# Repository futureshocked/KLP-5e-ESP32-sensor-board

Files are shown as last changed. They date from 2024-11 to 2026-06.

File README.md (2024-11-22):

View this project on [CADLAB.io](https://cadlab.io/project/28685). 

## Project Summary: Custom IoT PCB with ESP32-C3-02 and TP4056 Li-ion Charger

This project involves the design and development of a custom PCB for an IoT application powered by the ESP32-C3-02 SoC. The board includes integrated power management features using the TP4056 Li-ion battery charger IC, enabling efficient and safe charging of a single-cell Li-ion battery.

### Key Features

- **Microcontroller**: ESP32-C3-02 SoC for Wi-Fi and BLE connectivity.
- **Power Management**: TP4056 IC for single-cell Li-ion battery charging with thermal regulation.
- **Battery Protection**: Integrated under-voltage lockout and trickle charging.
- **Sensors and Modules**:
  - BME280 for temperature, humidity, and pressure sensing.
  - Ambient light and sound sensors.
  - Mini SD card reader for data storage.
  - Flash memory for additional storage.
- **Display**: I2C OLED for real-time data visualization.
- **Power Inputs**:
  - USB-C connector for charging and data transfer.
  - LiPo battery connector with onboard charging circuitry.
- **Indicators**: LED indicators for charge status (charging and full).

### Design Highlights

1. **Power Supply Integration**:
   - USB-C provides power for both charging and system operation.
   - TP4056 handles battery charging and protection.
   - Power supplied to the ESP32-C3-02 is regulated for stability.

2. **Modular Architecture**:
   - Supports various sensors and peripherals for IoT applications.
   - Expandable via additional I2C devices.

3. **Safe and Efficient Charging**:
   - Programmable charging current using an external resistor.
   - Automatic charge termination and battery protection.

4. **Compact and Reliable Layout**:
   - Optimized PCB traces for minimal power loss.
   - Thermal management for the TP4056 and other components.

### Applications

- IoT edge devices for environmental monitoring.
- Battery-powered data logging systems.
- Prototyping platform for ESP32-based projects.

### Repository Contents

- **Schematic and PCB Layout**: KiCad files for the board design.
- **Firmware**: Source code for the ESP32-C3-02 to interface with sensors and peripherals.
- **Documentation**:
  - Datasheets for the TP4056 and other components.
  - Assembly instructions.
  - Testing procedures.
- **License**: MIT License.

This repository is a complete resource for designing and building a robust IoT solution with integrated power management and ESP32 connectivity.

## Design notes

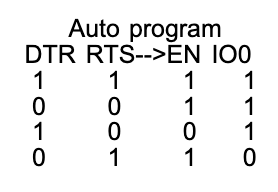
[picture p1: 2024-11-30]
KiCad project/Images/Auto program truth table.png

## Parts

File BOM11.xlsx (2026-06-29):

DESIGNATOR | QTY | VALUE | MPN | MANUFACTURER | Procurement Type | PACKAGE | DESCRIPTION
> C1, C2, C5, C8, C10, C13-C16, C18, C20, C21 | 12 | 0.1u | C0805C104K4RAC | KEMET | C | 805 | Multilayer Ceramic Capacitors MLCC - SMD/SMT 16V 0.1uF X7R 0805 10%
> C3, C4, C7, C12 | 4 | 10u | T491A106K010AT7280 | KEMET | C | 1206 | T491, Tantalum, MnO2 Tantalum, Commercial Grade, 10 uF, 10%, 10 VDC, 125C, -55C, 85C, SMD, MnO2, Molded, 6 % , 3.8 Ohms, 1000 nA, 58.6 mg, 3216, 1.6mm, Height Max = 1.8mm, 9000, 156 Weeks
> C6, C11, C19, C22 | 4 | 1u | C0805C105K4RACTU | KEMET | C | 805 | Multilayer Ceramic Capacitors MLCC - SMD/SMT 16V 1uF X7R 0805 10%
C9 | 1 | 4.7u | T491A475K010AT7280 | KEMET | C | 1206 | T491, Tantalum, MnO2 Tantalum, Commercial Grade, 4.7 uF, 10%, 10 VDC, 125C, -55C, 85C, SMD, MnO2, Molded, 6 % , 4 Ohms, 500 nA, 58.6 mg, 3216, 1.6mm, Height Max = 1.8mm, 9000, 156 Weeks
C17 | 1 | 10n | C0805C103M4RACTU | KEMET | C | 805 | Multilayer Ceramic Capacitors MLCC - SMD/SMT 16V 0.01uF X7R 0805 20%
> D1, D4, D6 | 3 | RED | LTST-C170KRKT | Lite-On | C | 805 | Standard LEDs - SMD Red Clear 631nm
> D2, D5 | 2 | GREEN | LTST-C170GKT | Lite-On | C | 805 | LED,SMD,0805,Green,6mcd,130deg Lite-On LTST-C170GKT, CHIPLED 0805 Series Green LED, 569 nm 2012 (0805), Rectangle Lens SMD package
D3 | 1 | BLUE | LTST-C170TBKT | Lite-On | C | 805 | LED,SMD,0805,Blue,28mcd,130deg
F1 | 1 | 0ZCH0110AF2E | 0ZCH0110AF2E | Belfuse | C | 1210 | 1210 SMT PPTC | 1.10 Ih | 16V
J1 | 1 | USB_C_Receptacle | Footprints:BELFUSE_SS-52400-002 | BELFUSE Stewart Connector | SS-52400-003 for standard 1.6 mm PCB thickness | USB 2.0-only Type-C Receptacle connector. See https://www.snapeda.com/parts/SS-52400-002/Bel%20Fuse/view-part/?ref=search&t=BELFUSE_SS-52400-002
J2 | 1 | JST_2mm_LiPo | JST_B2B-PH-SM4-TB | JST | C |  | 2 Pin 2mm JST Battery Connector
J3 | 1 | GSD090012SEU | GSD090012SEU | Amphenol | C |  | Memory Card Connectors SD CARD CONNECTOR 9 POS, SMT
> J4, J5 | 2 | B4B-XH-AM | B4B-XH-AM | JST | C |  | Connector header vertical 4pos 2.5mm
J6 | 1 | Conn_01x05 | PZ254V-11-05P |  | C |  | Header 1X5, 2.54mm
MK1 | 1 | CMC-5042PF-AC | CMC-5042PF-AC | CUI INC | C |  | Microphone
Q1 | 1 | TEMT6000X01 | TEMT6000X01 | VISHAY | C | 4 mm x 2 mm x 1.05 mm | Ambient Light Sensors Ambient Light Sensor AEC-Q101 Qualified
> Q2, Q3 | 2 | BC817 | BC817 |  | C | SOT-23 | 0.8A Ic, 45V Vce, NPN Transistor, SOT-23
> R1, R2, R19, R23, R30, R32-R34 | 8 | 10K | 0805W8F1002T5E |  | C | 805 | SMD resistor, 0805, 125mW, 1%
> R3, R4 | 2 | 5k1 | 0805W8F5101T5E |  | C | 0805 | SMD resistor, 0805, 125mW, 1%
> R5, R26, R28 | 3 | 2K | 0805W8F2001T5E |  | C | 0805 | SMD resistor, 0805, 125mW, 1%
R6 | 1 | 20K | 0805W8F2002T5E |  | C | 0805 | SMD resistor, 0805, 125mW, 1%
> R7-R9 | 3 | 470 | 0805W8F4700T5E |  | C | 0805 | SMD resistor, 0805, 125mW, 1%
> R10, R14, R18 | 3 | 330 | 0805W8F3300T5E |  | C | 0805 | SMD resistor, 0805, 125mW, 1%
R11 | 1 | 1K | 0805W8F1001T5E |  | C | 0805 | SMD resistor, 0805, 125mW, 1%
R12 | 1 | 22K1 | FRC0805F2212TS |  | C | 0805 | SMD resistor, 0805, 125mW, 1%
R13 | 1 | 47K5 | 0805W8F4752T5E |  | C | 0805 | SMD resistor, 0805, 125mW, 1%
> R15-R17, R20-R22 | 6 | 50 | ARG05FTC0500 |  | C | 0805 | SMD resistor, 0805, 125mW, 1%
> R24, R25 | 2 | 4K7 | 0805W8F4701T5E |  | C | 0805 | SMD resistor, 0805, 125mW, 1%
> R27, R29 | 2 | 1M | CRCW08051M00FKEA |  | C | 0805 | SMD resistor, 0805, 125mW, 1%
R31 | 1 | 100K | 0805W8F1003T5E |  | C | 0805 | SMD resistor, 0805, 125mW, 1%
> SW1, SW2 | 2 | 1101NE | USLPT2819 Family | TE Connectivity | USLPT2819 MSLPT (Mini size) | SMD_6x3.5mm_h2.5mm. Please see https://www.snapeda.com/parts/USLPT2819DT2TR/TE%20Connectivity/view-part/?ref=search&t=SMD%20switch
U1 | 1 | MCP73871 | MCP73871-4CCI/ML | Microchip | C | QFN-20 | Single cell, Li-Ion/Li-Po charge management controller
U2 | 1 | LM1117MPX-3.3_NOPB | LM1117MPX-3.3/NOPB | Texas Instruments | C | SOT-223-4 | Space saving 800-mA low-dropout linear regulator with internal current limit
U3 | 1 | ESP32-C3-WROOM-02-H4 | ESP32-C3-WROOM-02-H4 | Espressif | C |  | Multiprotocol Modules SMD module, ESP32-C3, 4MB SPI flash, PCB antenna
U4 | 1 | CP2102N-A02-GQFN20 | CP2102N-A02-GQFN20 | Silicon Laboratories | C | QFN20 | USB to UART Bridge
U5 | 1 | USBLC6-2SC6 | USBLC6-2SC6 | STMicroelectronics | C | SOT-23-6 | ESD Suppressors / TVS Diodes ESD Protection Low Cap
U6 | 1 | W25Q32JVSSIQ | W25Q32JVSSIQ | Winbond | C | SOIC-8 | NOR Flash spiFlash, 32M-bit, 4Kb Uniform Sector
U7 | 1 | BME280 | BME280 | Bosch | C | LGA-8 | Air Quality Sensor MEMS humidity, pressure and temperature sensor
U8 | 1 | MAX4466EXK+T | MAX4466EXK+T | Analog Devices Inc. | C | SC-70-5 | Microphone Preamplifier

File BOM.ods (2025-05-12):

DESIGNATOR | QTY | VALUE | MANUF. PART No | MANUFACTURER | PACKAGE | DESCRIPTION
C1, C2, C5, C8, C10, C13-C16, C18, C21, C23 | 12 | 0.1u | C0805C104K4RAC | KEMET | 0805 | Multilayer Ceramic Capacitors MLCC - SMD/SMT 16V 0.1uF X7R 0805 10%
C3, C4, C7, C12 | 4 | 10u | T491A106K010AT7280 | KEMET | 1206 | T491, Tantalum, MnO2 Tantalum, Commercial Grade, 10 uF, 10%, 10 VDC, 125C, -55C, 85C, SMD, MnO2, Molded, 6 % , 3.8 Ohms, 1000 nA, 58.6 mg, 3216, 1.6mm, Height Max = 1.8mm, 9000, 156 Weeks
C6, C11, C22 | 3 | 1u | C0805C105K4RACTU | KEMET | 0805 | Multilayer Ceramic Capacitors MLCC - SMD/SMT 16V 1uF X7R 0805 10%
C9 | 1 | 4.7u | T491A475K010AT7280 | KEMET | 1206 | T491, Tantalum, MnO2 Tantalum, Commercial Grade, 4.7 uF, 10%, 10 VDC, 125C, -55C, 85C, SMD, MnO2, Molded, 6 % , 4 Ohms, 500 nA, 58.6 mg, 3216, 1.6mm, Height Max = 1.8mm, 9000, 156 Weeks
C17, C24, C25 | 3 | 10n | C0603C103K4RACTU | KEMET | 0603 | Multilayer Ceramic Capacitors MLCC - SMD/SMT 16V 0.01uF X7R 0603 10%
C19 | 1 | 10uF | C1206C106K4RAC | KEMET | 1206 | Multilayer Ceramic Capacitors MLCC - SMD/SMT 16V 10uF X7R 1206 10%
C20 | 1 | 100pF | C0603C101K4RACTU | KEMET | 0603 | Multilayer Ceramic Capacitors MLCC - SMD/SMT 16V 100pF X7R 0603 10%
D1, D4, D6 | 3 | RED | LTST-C170KRKT | Lite-On | 0805 | Standard LEDs - SMD Red Clear 631nm
D2, D5 | 2 | GREEN | LTST-C170GKT | Lite-On | 0805 | LED,SMD,0805,Green,6mcd,130deg Lite-On LTST-C170GKT, CHIPLED 0805 Series Green LED, 569 nm 2012 (0805), Rectangle Lens SMD package
D3 | 1 | BLUE | LTST-C170TBKT | Lite-On | 0805 | LED,SMD,0805,Blue,28mcd,130deg
F1 | 1 | 0ZCH0110AF2E | 0ZCH0110AF2E | Belfuse | 1210 | 1210 SMT PPTC | 1.10 Ih | 16V
J1 | 1 | USB_C_Receptacle | SS-52400-002 | STEWART CONNECTOR | USB Type-C | USB 2.0-only Type-C Receptacle connector
J2 | 1 | JST_2mm_LiPo | PHR-2 | JST |  | 2 Pin 2mm JST Battery Connector
J3 | 1 | GSD090012SEU | GSD090012SEU | Amphenol |  | Memory Card Connectors SD CARD CONNECTOR 9 POS, SMT
J4, J5 | 2 | B4B-XH-AM | B4B-XH-AM | JST |  | Connector header vertical 4pos 2.5mm
J6 | 1 | Conn_01x05 |  |  |  | Header 1X5, 2.54mm
L1 | 1 |  | FBMJ2125HM330 | TAIYO YUDEN | 0805 | Ferrite Bead 0805 4A 33OHMS 25%
MK1 | 1 | CMC-5042PF-AC | CMC-5042PF-AC | CUI INC
Q1 | 1 | TEMT6000X01 | TEMT6000X01 | VISHAY | 4 mm x 2 mm x 1.05 mm | Ambient Light Sensors Ambient Light Sensor AEC-Q101 Qualified
Q2, Q3 | 2 | BC817 | BC817 |  | SOT-23 | 0.8A Ic, 45V Vce, NPN Transistor, SOT-23
R1, R2, R19, R23, R32-R34 | 7 | 10K |  |  | 805 | SMD resistor, 0805, 125mW, 1%
R3, R4 | 2 | 5k1 |  |  | 0805 | SMD resistor, 0805, 125mW, 1%
R5, R26, R28 | 3 | 2K |  |  | 0805 | SMD resistor, 0805, 125mW, 1%
R6 | 1 | 20K |  |  | 0805 | SMD resistor, 0805, 125mW, 1%
R7-R9 | 3 | 470 |  |  | 0805 | SMD resistor, 0805, 125mW, 1%
R10, R14, R18 | 3 | 330 |  |  | 0805 | SMD resistor, 0805, 125mW, 1%
R11, R30 | 2 | 1K |  |  | 0805 | SMD resistor, 0805, 125mW, 1%
R12 | 1 | 22K1 |  |  | 0805 | SMD resistor, 0805, 125mW, 1%
R13 | 1 | 47K5 |  |  | 0805 | SMD resistor, 0805, 125mW, 1%
R15-R17, R20-R22 | 6 | 50 |  |  | 0805 | SMD resistor, 0805, 125mW, 1%
R24, R25 | 2 | 4K7 |  |  | 0805 | SMD resistor, 0805, 125mW, 1%
R27, R29 | 2 | 1M |  |  | 0805 | SMD resistor, 0805, 125mW, 1%
R31 | 1 | 22K |  |  | 0805 | SMD resistor, 0805, 125mW, 1%
SW1, SW2 | 2 | TL3305AF260QG | TL3305AF260QG | E-Switch |  | Tactile Switches 50mA 12VDC SPST, NO 3.8mm Act 260gf
U1 | 1 | MCP73871 | MCP73871-4CCI/ML | Microchip | QFN-20 | Single cell, Li-Ion/Li-Po charge management controller
U2 | 1 | LM1117MPX-3.3_NOPB | LM1117MPX-3.3/NOPB | Texas Instruments | SOT-223-4 | Space saving 800-mA low-dropout linear regulator with internal current limit
U3 | 1 | ESP32-C3-WROOM-02-H4 | ESP32-C3-WROOM-02-H4 | Espressif |  | Multiprotocol Modules SMD module, ESP32-C3, 4MB SPI flash, PCB antenna
U4 | 1 | CP2102N-A02-GQFN20 | CP2102N-A02-GQFN20 | Silicon Laboratories | QFN20 | USB to UART Bridge
U5 | 1 | USBLC6-2SC6 | USBLC6-2SC6 | STMicroelectronics | SOT-23-6 | ESD Suppressors / TVS Diodes ESD Protection Low Cap
U6 | 1 | W25Q32JVSSIQ | W25Q32JVSSIQ | Winbond | SOIC-8 | NOR Flash spiFlash, 32M-bit, 4Kb Uniform Sector
U7 | 1 | BME280 | BME280 | Bosch | LGA-8 | Air Quality Sensor MEMS humidity, pressure and temperature sensor
U8 | 1 | MAX4466EXK+T | MAX4466EXK+T | Analog Devices Inc. | SC-70-5 | Microphone Preamplifier
VR1 | 1 | 35WR100KLFTR | 35WR100KLFTR | TT Electronics |  | Trimmer Resistor - SMD 3mm 100K Open Type

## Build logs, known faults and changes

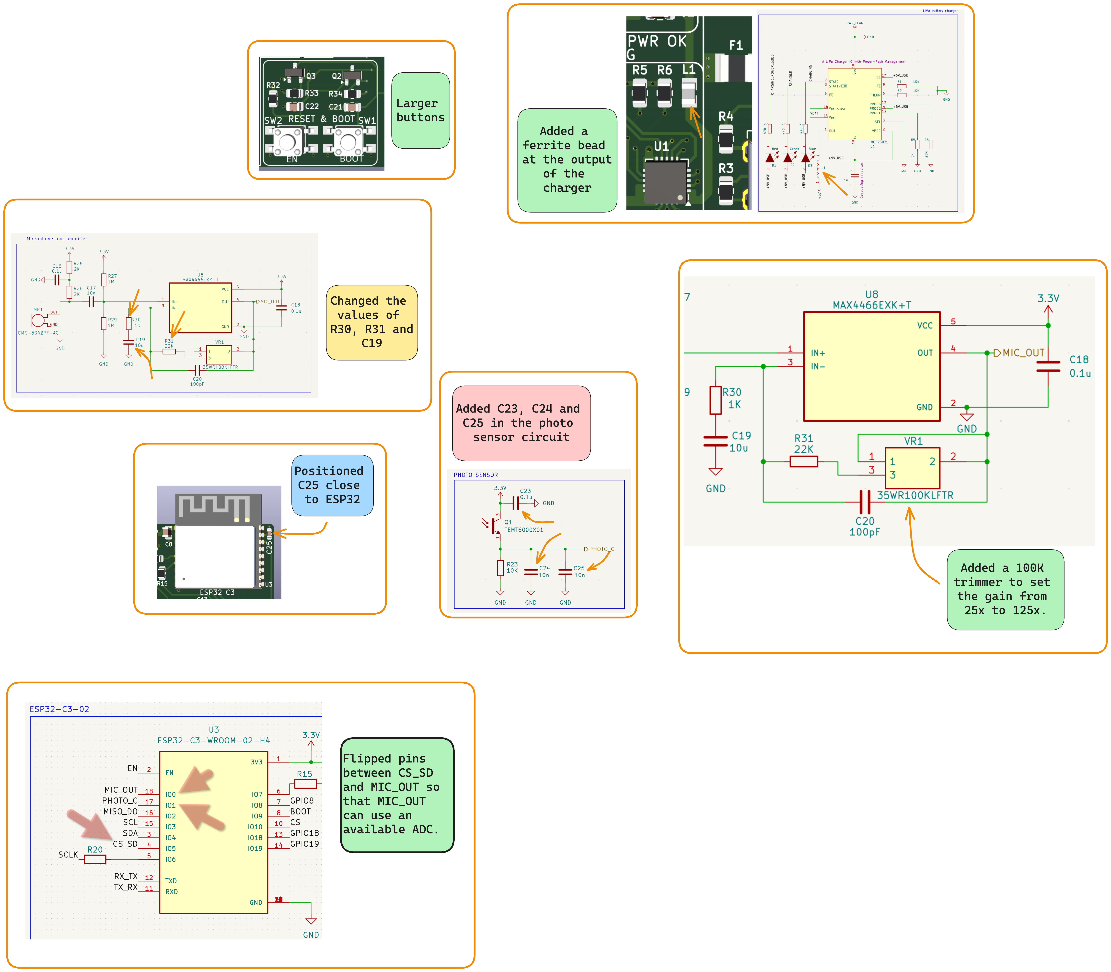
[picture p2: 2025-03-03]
ESP32 PCB prototype 2 improvements and fixes.png

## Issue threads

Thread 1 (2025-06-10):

Any solution found for the CP2102 TX, RX LEDs not blinking on data communication ?

rickygai, 2025-06-10:
at Udemy video Section 4, 25.210 13:01, the R14 and R18 is 470 ohm, based on latest schematic downloaded and in this video, R14 and R18 changed to 330ohm.

Does this change resolve the blinking problem of TX and RX LEDs of CP2102 ?

a1wolfe, 2025-09-07:
Hi Ricky, I had my board built with 330 ohms and that did not resolve the issue.

The real issue is that the CP2102 GPIO pins are configured as inputs by default (Section 4.3.1 of datasheet). The TXT/RXT blinking behaviors are alternate functions for GPIO.2 and GPIO.3.

The only way I found to reconfigure the CP2102 GPIO function is using Simplicity Studio by Silicon Labs. You can download the installers here: https://www.silabs.com/software-and-tools/simplicity-studio

After installation, open Simplicity Studio and connect your board. The CP2102 should show up, and you can then select the tab for compatible software. This will take you to another sub-tool called Xpress Configurator.

In Xpress Configuration, here is where you can change the alternate function mode for the GPIOs.

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

The tools are pretty intuitive, but there is an app note from Silicon Labs here with more info: https://www.silabs.com/documents/public/application-notes/AN721.pdf

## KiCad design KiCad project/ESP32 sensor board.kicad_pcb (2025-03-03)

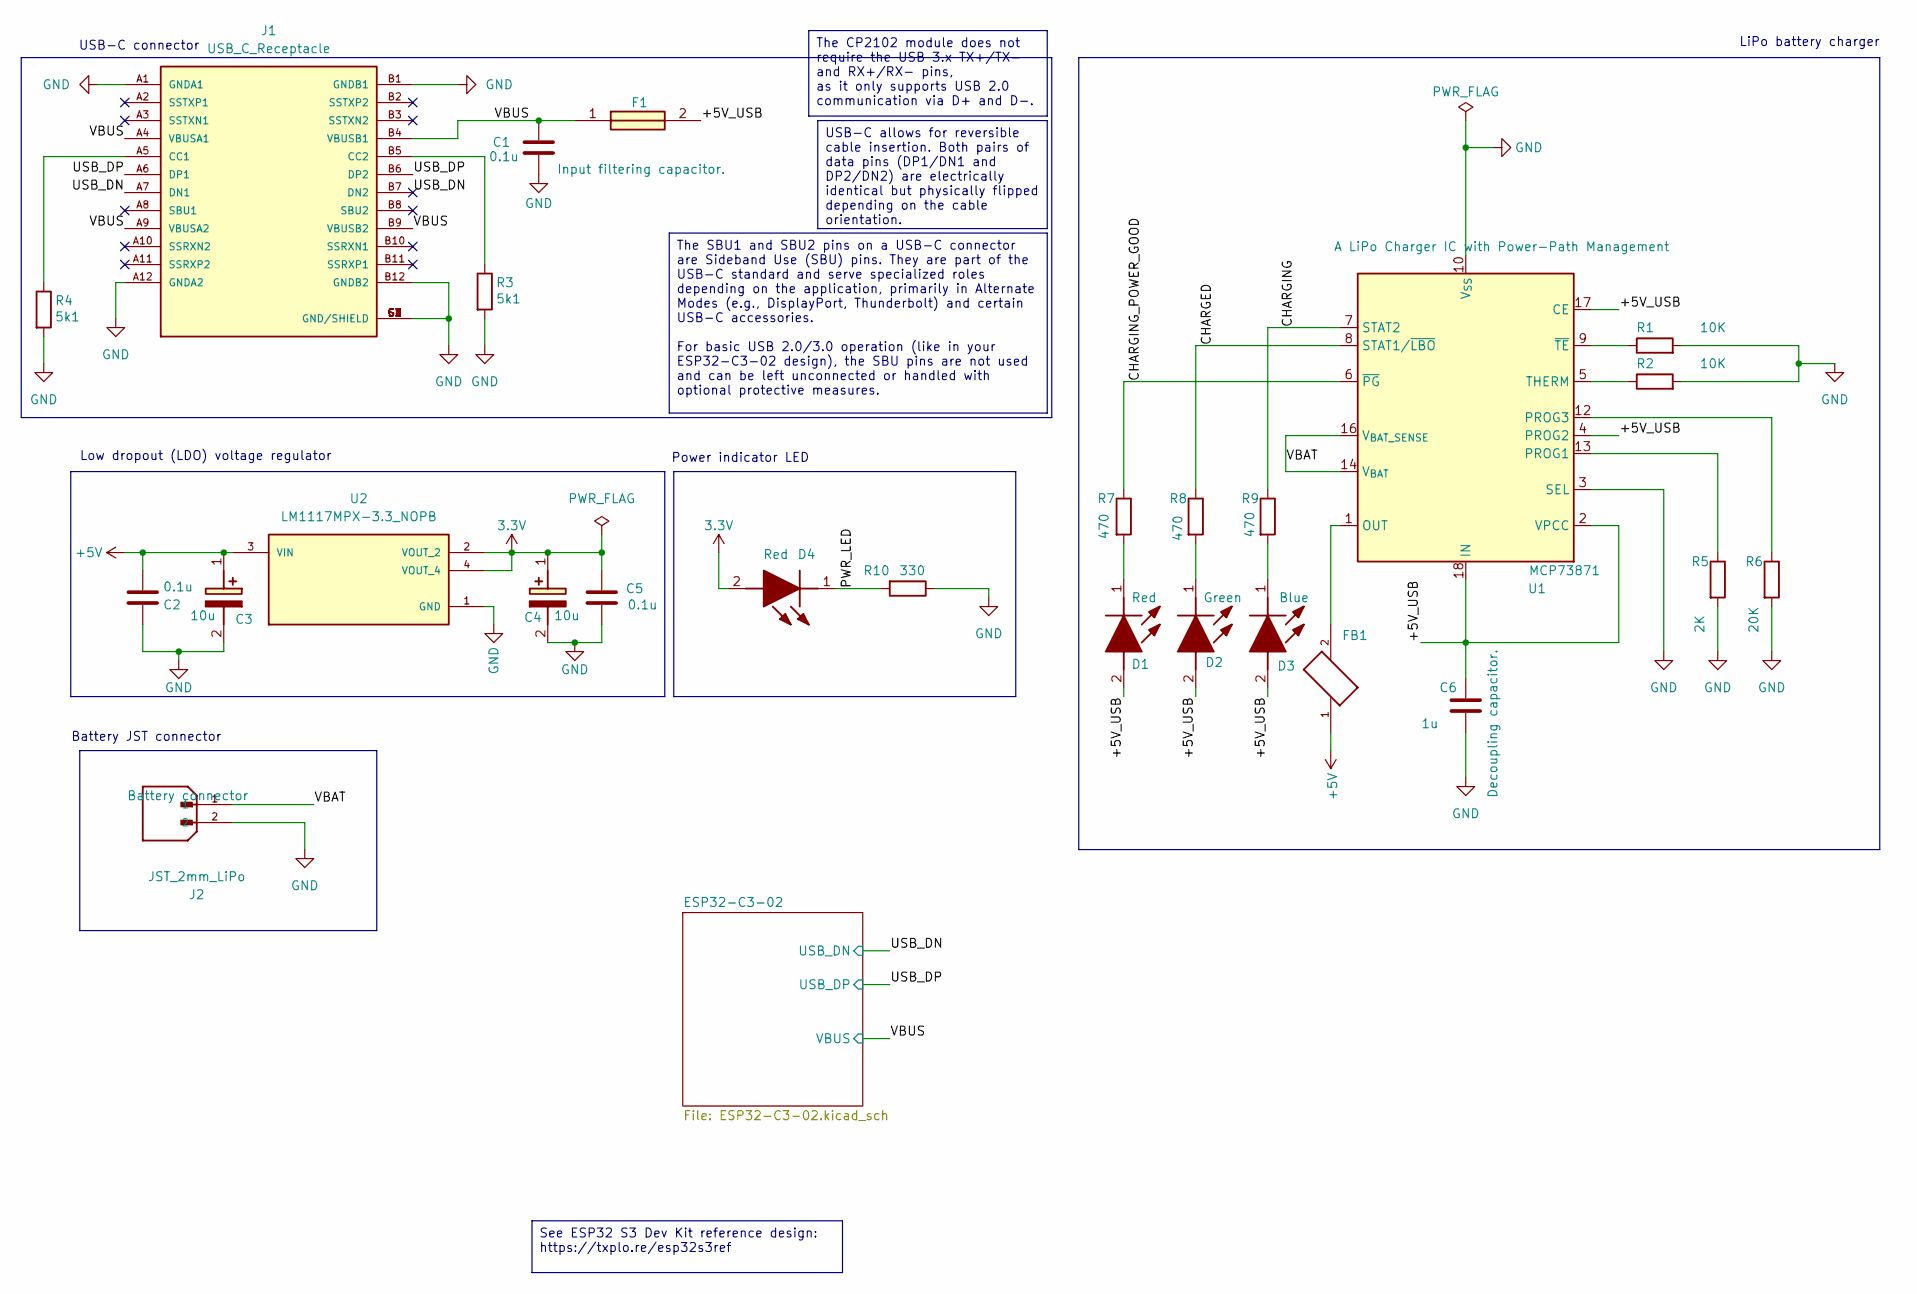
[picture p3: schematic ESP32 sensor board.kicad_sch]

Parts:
C1, C2, C5: 0.1u; C_0805_2012Metric; Voltage 1kV; Tolerance 100%
C3, C4: 10u; T491A; Voltage 1kV; Tolerance 100%; Manufacturer_Part_Number T491A106K010AT7280; Mouser Part Number 80-T491A106K107280
C6: 1u; C_0805_2012Metric; Voltage 1kV; Tolerance 100%
D1, D4: Red; LEDC2012X120N; Manufacturer_Part_Number LTST-C170KRKT; Mouser Part Number 859-LTST-C170KRKT
D2: Green; LEDC2012X120N; Manufacturer_Part_Number LTST-C170GKT; Mouser Part Number 859-LTST-C170GKT
D3: Blue; LEDC2012X120N; Manufacturer_Part_Number LTST-C170TBKT; Mouser Part Number 859-LTST-C170TBKT
F1: 0ZCH0110AF2E; FUSC3226X100N; Manufacturer_Part_Number 0ZCH0110AF2E
FB1: FBMJ2125HM330-T; BEADC2012X105N
J1: USB_C_Receptacle; BELFUSE_SS-52400-002; PARTREV A0
J2: JST_2mm_LiPo; JST_B2B-PH-SM4-TB; Manufacturer_Part_Number ?
R1, R2: 10K; R_0805_2012Metric
R3, R4: 5k1; R_0805_2012Metric
R5: 2K; R_0805_2012Metric
R6: 20K; R_0805_2012Metric
R7, R8, R9: 470; R_0805_2012Metric
R10: 330; R_0805_2012Metric
U1: MCP73871; QFN-20-1EP_4x4mm_P0.5mm_EP2.5x2.5mm; Manufacturer_Part_Number MCP73871-4CCI/ML
U2: LM1117MPX-3.3_NOPB; VREG_LM1117MPX-3.3; Mouser Part Number 926-LM1117MPX3.3NOPB

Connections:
3.3V: C4.1 (+), C5.1, D4.2 (A), U2.2 (VOUT_2), U2.4 (VOUT_4); also elsewhere on the board
+5V: C2.1, C3.1 (+), FB1.1, U2.3 (VIN)
/+5V_USB: C6.1, D1.2 (A), D2.2 (A), D3.2 (A), F1.2, U1.2 (VPCC), U1.4 (PROG2), U1.17 (CE), U1.18 (IN), U1.19 (IN)
/CHARGED: R8.1, U1.8 (STAT1/~LBO)
/CHARGING: R9.1, U1.7 (STAT2)
/CHARGING_POWER_GOOD: R7.1, U1.6 (~PG)
/PWR_LED: D4.1 (K), R10.2
/USB_DN: J1.A7 (DN1), J1.B7 (DN2); also elsewhere on the board
/USB_DP: J1.A6 (DP1), J1.B6 (DP2); also elsewhere on the board
/VBAT: J2.1, U1.14 (V_{BAT}), U1.15 (V_{BAT}), U1.16 (V_{BAT_SENSE})
/VBUS: C1.1, F1.1, J1.A4 (VBUSA1), J1.A9 (VBUSA2), J1.B4 (VBUSB1), J1.B9 (VBUSB2); also elsewhere on the board
GND: C1.2, C2.2, C3.2 (-), C4.2 (-), C5.2, C6.2, J1.A1 (GNDA1), J1.A12 (GNDA2), J1.B1 (GNDB1), J1.B12 (GNDB2), J1.G1 (GND/SHIELD), J1.G2 (GND/SHIELD), J1.G3 (GND/SHIELD), J1.G4 (GND/SHIELD), J1.S1 (GND/SHIELD), J1.S2 (GND/SHIELD), J1.S3 (GND/SHIELD), J1.S4 (GND/SHIELD), J2.2, R1.2, R2.2, R3.2, R4.2, R5.2, R6.2, R10.1, U1.3 (SEL), U1.10 (V_{SS}), U1.11 (V_{SS}), U1.21 (V_{SS}), U2.1 (GND); also elsewhere on the board
unnamed: D1.1 (K), R7.2
unnamed: D2.1 (K), R8.2
unnamed: D3.1 (K), R9.2
unnamed: FB1.2, U1.1 (OUT), U1.20 (OUT)
unnamed: J1.A5 (CC1), R4.1
unnamed: J1.B5 (CC2), R3.1
unnamed: R5.1, U1.13 (PROG1)
unnamed: R6.1, U1.12 (PROG3)
unnamed: R2.1, U1.5 (THERM)
unnamed: R1.1, U1.9 (~TE)

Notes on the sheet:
USB-C connector
LiPo battery charger
Power indicator LED
Low dropout (LDO) voltage regulator
Battery JST connector
The CP2102 module does not require the USB 3.x TX+/TX- and RX+/RX- pins, as it only supports USB 2.0 communication via D+ and D-.
See ESP32 S3 Dev Kit reference design: https://txplo.re/esp32s3ref
The SBU1 and SBU2 pins on a USB-C connector are Sideband Use (SBU) pins. They are part of the USB-C standard and serve specialized roles depending on the application, primarily in Alternate Modes (e.g., DisplayPort, Thunderbolt) and certain USB-C accessories. For basic USB 2.0/3.0 operation (like i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
USB-C allows for reversible cable insertion. Both pairs of data pins (DP1/DN1 and DP2/DN2) are electrically identical but physically flipped depending on the cable orientation.

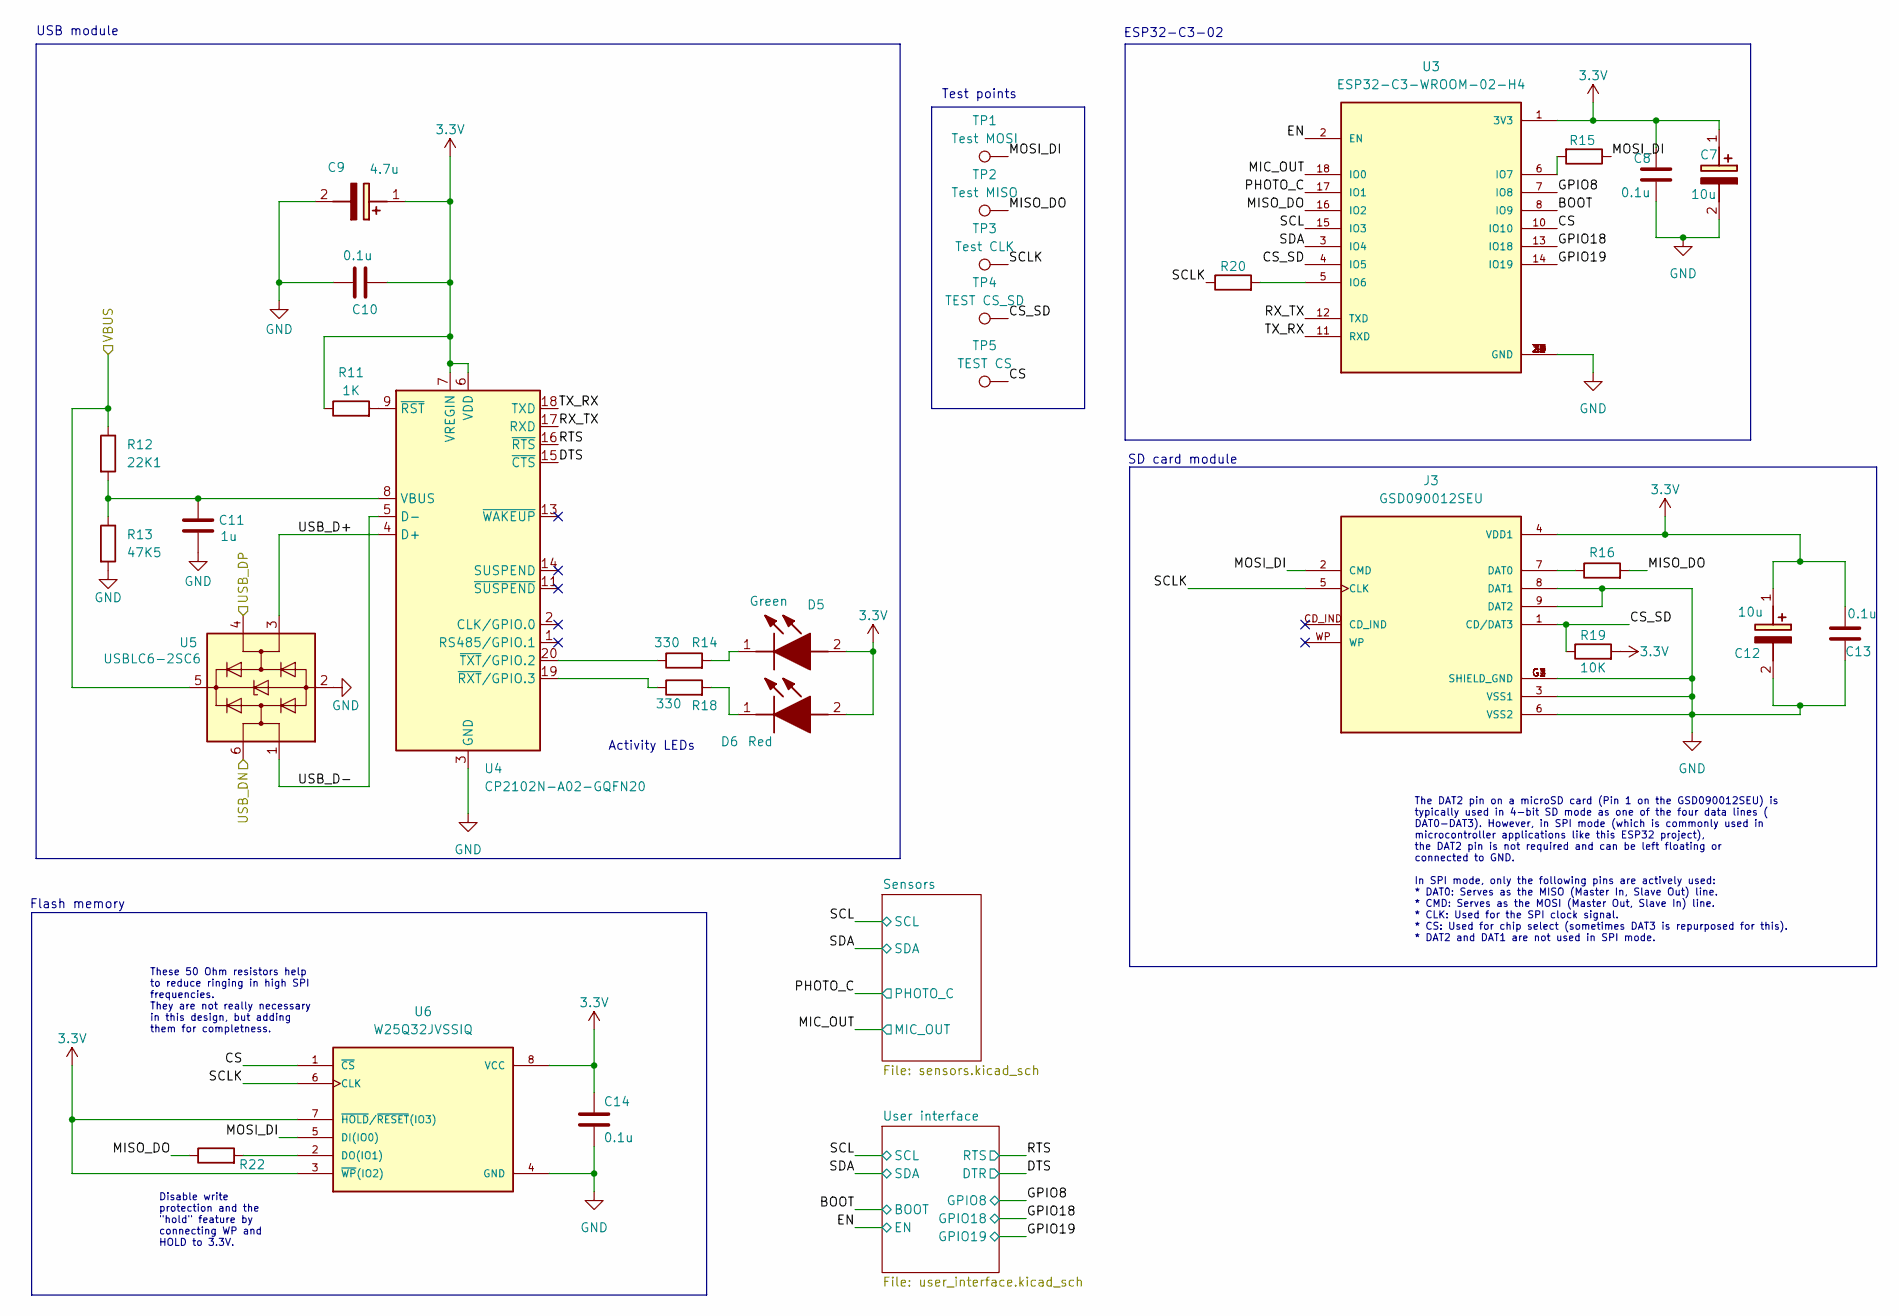
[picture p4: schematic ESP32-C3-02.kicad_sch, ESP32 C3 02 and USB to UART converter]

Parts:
C7, C12: 10u; T491A; Voltage 1kV; Tolerance 100%; Manufacturer_Part_Number T491A106K010AT7280; Mouser Part Number 80-T491A106K107280
C8, C10, C13, C14: 0.1u; C_0805_2012Metric; Voltage 1kV; Tolerance 100%
C9: 4.7u; T491A; Voltage 1kV; Tolerance 100%; Manufacturer_Part_Number T491A106K010AT7280; Mouser Part Number 80-T491A106K107280
C11: 1u; C_0805_2012Metric; Voltage 1kV; Tolerance 100%
D5: Green; LEDC2012X120N; Manufacturer_Part_Number LTST-C170GKT; Mouser Part Number 859-LTST-C170GKT
D6: Red; LEDC2012X120N; Manufacturer_Part_Number LTST-C170KRKT; Mouser Part Number 859-LTST-C170KRKT
J3: GSD090012SEU; AMPHENOL_GSD090012SEU; PARTREV E
R11: 1K; R_0805_2012Metric
R12: 22K1; R_0805_2012Metric
R13: 47K5; R_0805_2012Metric
R14, R18: 330; R_0805_2012Metric
R15, R16, R20, R22: 50; R_0805_2012Metric
R19: 10K; R_0805_2012Metric
TP1: Test MOSI; TestPoint_Pad_D1.0mm
TP2: Test MISO; TestPoint_Pad_D1.0mm
TP3: Test CLK; TestPoint_Pad_D1.0mm
TP4: TEST CS_SD; TestPoint_Pad_D1.0mm
TP5: TEST CS; TestPoint_Pad_D1.0mm
U3: ESP32-C3-WROOM-02-H4; MODULE_ESP32-C3-WROOM-02-H4; Manufacturer_Part_Number ESP32-C3-WROOM-02-H4
U4: CP2102N-A02-GQFN20; SiliconLabs_QFN-20-1EP_3x3mm_P0.5mm_EP1.8x1.8mm; Manufacturer_Part_Number CP2102N-A02-GQFN20
U5: USBLC6-2SC6; SOT-23-6; Manufacturer_Part_Number USBLC6-2SC6; Mouser Part Number 511-USBLC6-2SC6
U6: W25Q32JVSSIQ; SOIC127P790X216-8N; M_PART_NUMBER W25QXX

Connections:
3.3V: C7.1 (+), C8.1, C9.1 (+), C10.1, C12.1 (+), C13.2, C14.1, D5.2 (A), D6.2 (A), J3.4 (VDD1), R11.1, R19.2, U3.1 (3V3), U4.6 (VDD), U4.7 (VREGIN), U6.3 (~WP(IO2)), U6.7 (~HOLD/~RESET(IO3)), U6.8 (VCC); also elsewhere on the board
/ESP32-C3-02/BOOT: U3.8 (IO9); also elsewhere on the board
/ESP32-C3-02/CS: TP5.1, U3.10 (IO10), U6.1 (~CS)
/ESP32-C3-02/CS_SD: J3.1 (CD/DAT3), R19.1, TP4.1, U3.4 (IO5)
/ESP32-C3-02/DTS: U4.15 (~CTS); also elsewhere on the board
/ESP32-C3-02/EN: U3.2 (EN); also elsewhere on the board
/ESP32-C3-02/GPIO8: U3.7 (IO8); also elsewhere on the board
/ESP32-C3-02/GPIO18: U3.13 (IO18); also elsewhere on the board
/ESP32-C3-02/GPIO19: U3.14 (IO19); also elsewhere on the board
/ESP32-C3-02/MIC_OUT: U3.18 (IO0); also elsewhere on the board
/ESP32-C3-02/MISO_DO: R16.2, R22.1, TP2.1, U3.16 (IO2)
/ESP32-C3-02/MOSI_DI: J3.2 (CMD), R15.1, TP1.1, U6.5 (DI(IO0))
/ESP32-C3-02/PHOTO_C: U3.17 (IO1); also elsewhere on the board
/ESP32-C3-02/RTS: U4.16 (~RTS); also elsewhere on the board
/ESP32-C3-02/RX_TX: U3.12 (TXD), U4.17 (RXD)
/ESP32-C3-02/SCL: U3.15 (IO3); also elsewhere on the board
/ESP32-C3-02/SCLK: J3.5 (CLK), R20.1, TP3.1, U6.6 (CLK)
/ESP32-C3-02/SDA: U3.3 (IO4); also elsewhere on the board
/ESP32-C3-02/TX_RX: U3.11 (RXD), U4.18 (TXD)
/ESP32-C3-02/USB_D+: U4.4 (D+), U5.3 (I/O2)
/ESP32-C3-02/USB_D-: U4.5 (D-), U5.1 (I/O1)
/USB_DN: U5.6 (I/O1); also elsewhere on the board
/USB_DP: U5.4 (I/O2); also elsewhere on the board
/VBUS: R12.1, U5.5 (VBUS); also elsewhere on the board
GND: C7.2 (-), C8.2, C9.2 (-), C10.2, C11.2, C12.2 (-), C13.1, C14.2, J3.3 (VSS1), J3.6 (VSS2), J3.8 (DAT1), J3.9 (DAT2), J3.G1 (SHIELD_GND), J3.G2 (SHIELD_GND), J3.G3 (SHIELD_GND), J3.G4 (SHIELD_GND), R13.2, U3.9 (GND), U3.19 (GND), U3.20 (GND), U3.21 (GND), U3.22 (GND), U3.23 (GND), U3.24 (GND), U3.25 (GND), U3.26 (GND), U3.27 (GND), U3.28 (GND), U3.29 (GND), U3.30 (GND), U3.31 (GND), U3.32 (GND), U3.33 (GND), U3.34 (GND), U3.35 (GND), U3.36 (GND), U3.37 (GND), U3.38 (GND), U3.39 (GND), U4.3 (GND), U4.12 (GND), U4.21 (GND), U5.2 (GND), U6.4 (GND); also elsewhere on the board
unnamed: D5.1 (K), R14.2
unnamed: D6.1 (K), R18.2
unnamed: J3.7 (DAT0), R16.1
unnamed: R20.2, U3.5 (IO6)
unnamed: R15.2, U3.6 (IO7)
unnamed: C11.1, R12.2, R13.1, U4.8 (VBUS)
unnamed: R11.2, U4.9 (~RST)
unnamed: R18.1, U4.19 (~RXT/GPIO.3)
unnamed: R14.1, U4.20 (~TXT/GPIO.2)
unnamed: R22.2, U6.2 (DO(IO1))

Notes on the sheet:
SD card module
Activity LEDs
Flash memory
USB module
Test points
ESP32-C3-02
Disable write protection and the "hold" feature by connecting WP and HOLD to 3.3V.
The DAT2 pin on a microSD card (Pin 1 on the GSD090012SEU) is typically used in 4-bit SD mode as one of the four data lines ( DAT0-DAT3). However, in SPI mode (which is commonly used in microcontroller applications like this ESP32 project), the DAT2 pin is not required and can be left floating or c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
These 50 Ohm resistors help to reduce ringing in high SPI frequencies. They are not really necessary in this design, but adding them for completness.

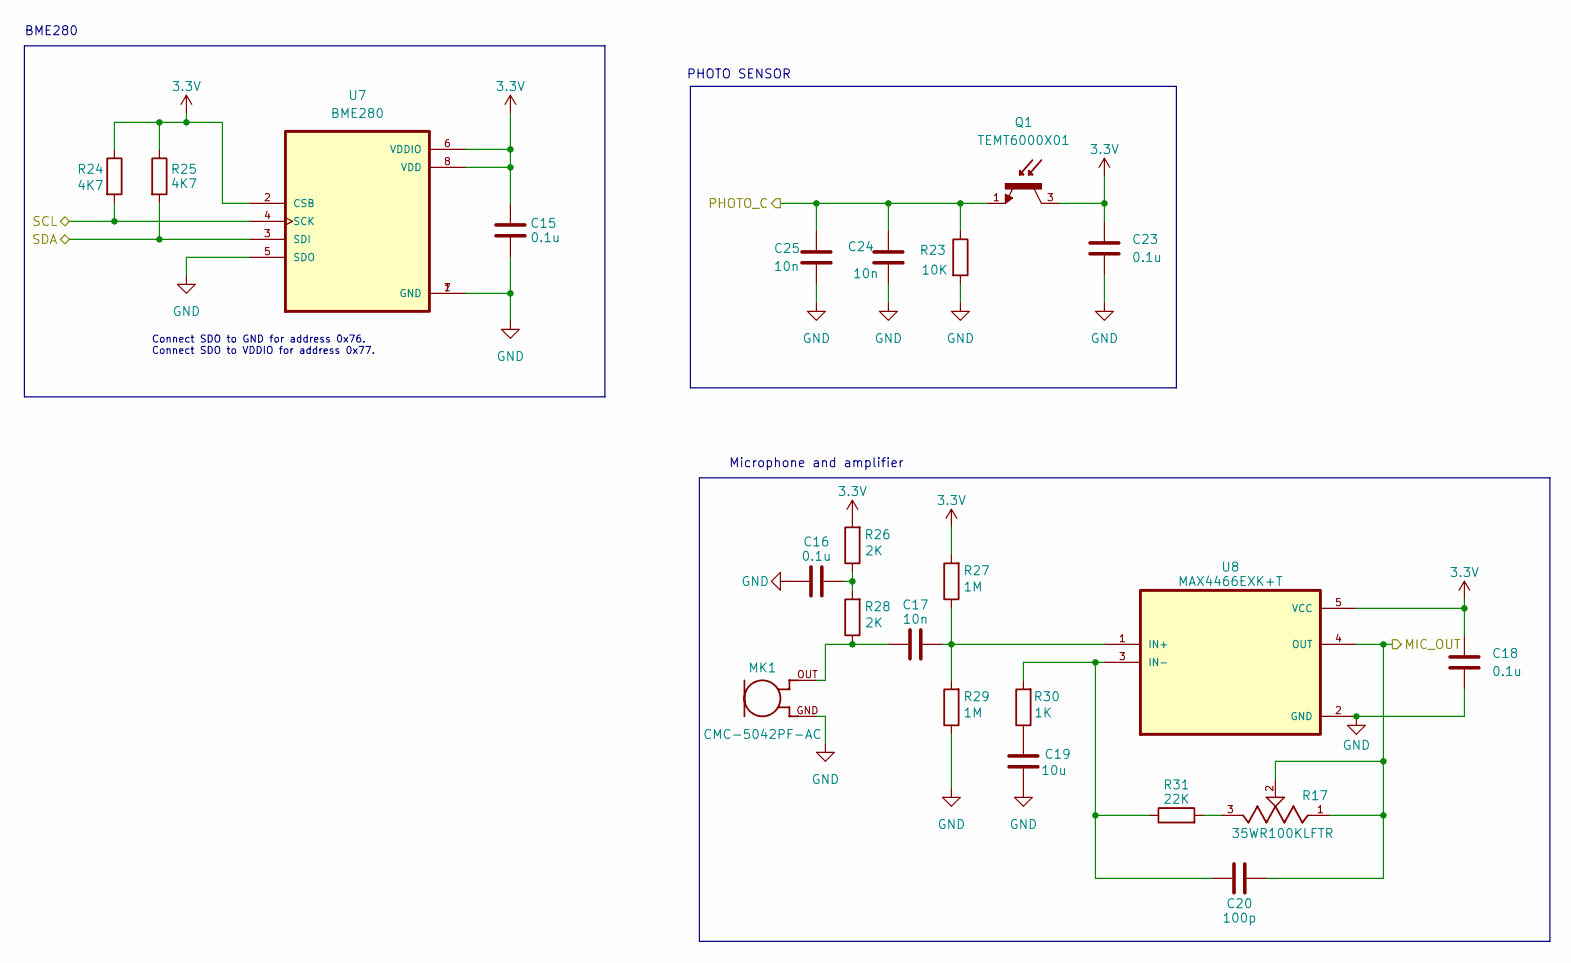
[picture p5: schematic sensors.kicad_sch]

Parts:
C15: 0.1u; C_0805_2012Metric; Voltage 1kV; Tolerance 100%
C16, C18, C23: 0.1u; C_0805_2012Metric
C17, C24, C25: 10n; C_0805_2012Metric
C19: 10u; C_0805_2012Metric
C20: 100p; C_0805_2012Metric
MK1: CMC-5042PF-AC; CUI_CMC-5042PF-AC; Manufacturer_Part_Number CMC-5042PF-AC
Q1: TEMT6000X01; TRANS_TEMT6000X01; PARTREV 1.9
R17: 35WR100KLFTR; TRIM_35WR100KLFTR; PARTREV D
R23: 10K; R_0805_2012Metric
R24, R25: 4K7; R_0805_2012Metric
R26, R28: 2K; R_0805_2012Metric
R27, R29: 1M; R_0805_2012Metric
R30: 1K; R_0805_2012Metric
R31: 22K; R_0805_2012Metric
U7: BME280; PSON65P250X250X100-8N; Manufacturer_Part_Number BME280
U8: MAX4466EXK+T; SOT65P210X110-5N; Manufacturer_Part_Number MAX4466EXK+T

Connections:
3.3V: C15.2, C18.1, C23.1, Q1.3, R24.1, R25.1, R26.2, R27.2, U7.2 (CSB), U7.6 (VDDIO), U7.8 (VDD), U8.5 (VCC); also elsewhere on the board
/ESP32-C3-02/MIC_OUT: C20.2, R17.1, R17.2, U8.4 (OUT); also elsewhere on the board
/ESP32-C3-02/PHOTO_C: C24.1, C25.1, Q1.1, R23.1; also elsewhere on the board
/ESP32-C3-02/SCL: R24.2, U7.4 (SCK); also elsewhere on the board
/ESP32-C3-02/SDA: R25.2, U7.3 (SDI); also elsewhere on the board
GND: C15.1, C16.2, C18.2, C19.1, C23.2, C24.2, C25.2, MK1.GND, R23.2, R29.1, U7.1 (GND), U7.5 (SDO), U7.7 (GND), U8.2 (GND); also elsewhere on the board
unnamed: C16.1, R26.1, R28.2
unnamed: C17.2, MK1.OUT, R28.1
unnamed: C19.2, R30.1
unnamed: R17.3, R31.2
unnamed: C17.1, R27.1, R29.2, U8.1 (IN+)
unnamed: C20.1, R30.2, R31.1, U8.3 (IN-)

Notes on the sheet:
PHOTO SENSOR
Microphone and amplifier
BME280
Connect SDO to GND for address 0x76. Connect SDO to VDDIO for address 0x77.

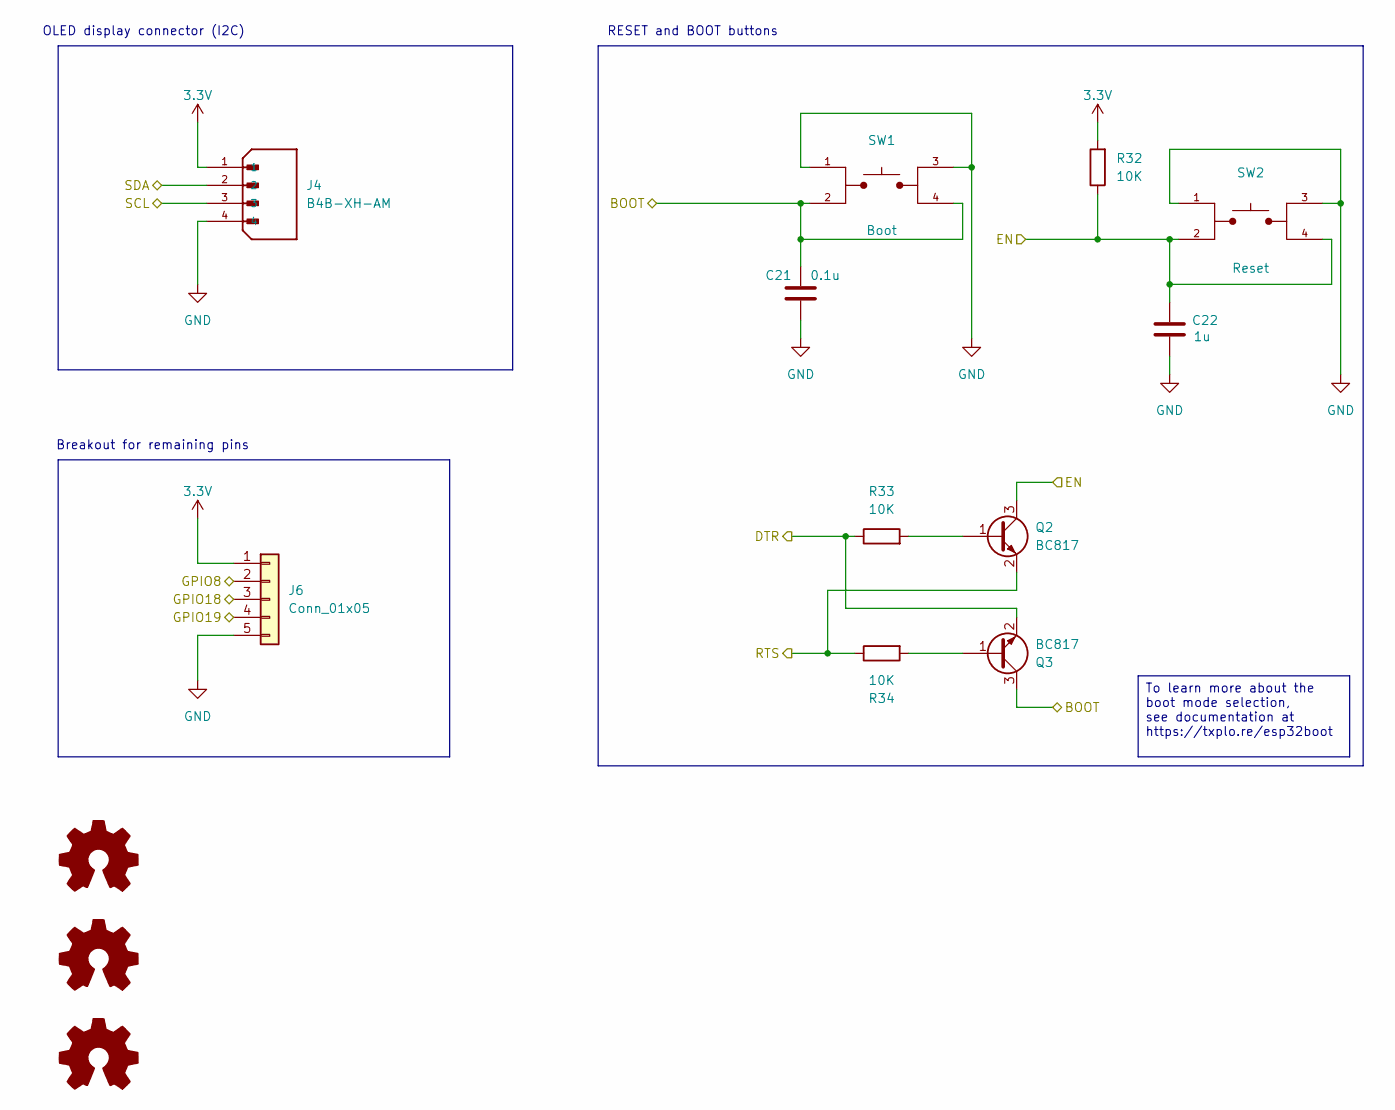
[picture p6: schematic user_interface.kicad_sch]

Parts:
C21: 0.1u; C_0805_2012Metric; Voltage 1kV; Tolerance 100%
C22: 1u; C_0805_2012Metric; Voltage 1kV; Tolerance 100%
J4: B4B-XH-AM; JST_B4B-XH-AM__LF__SN_; PARTREV N/A
J6: Conn_01x05; PinHeader_1x05_P2.54mm_Vertical
Q2, Q3: BC817; SOT-23; Manufacturer_Part_Number BC817
R32, R33, R34: 10K; R_0805_2012Metric
SW1, SW2: 1101NE; SW_TL3305AF260QG; Mfg Part# 8-004 SMD Button 8x3.6mm Height=2.5mm

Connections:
3.3V: J4.1, J6.1, R32.2; also elsewhere on the board
/ESP32-C3-02/BOOT: C21.1, Q3.3 (C), SW1.2, SW1.4; also elsewhere on the board
/ESP32-C3-02/DTS: Q3.2 (E), R33.1; also elsewhere on the board
/ESP32-C3-02/EN: C22.1, Q2.3 (C), R32.1, SW2.2, SW2.4; also elsewhere on the board
/ESP32-C3-02/GPIO8: J6.2; also elsewhere on the board
/ESP32-C3-02/GPIO18: J6.3; also elsewhere on the board
/ESP32-C3-02/GPIO19: J6.4; also elsewhere on the board
/ESP32-C3-02/RTS: Q2.2 (E), R34.1; also elsewhere on the board
/ESP32-C3-02/SCL: J4.3; also elsewhere on the board
/ESP32-C3-02/SDA: J4.2; also elsewhere on the board
GND: C21.2, C22.2, J4.4, J6.5, SW1.1, SW1.3, SW2.1, SW2.3; also elsewhere on the board
unnamed: Q2.1 (B), R33.2
unnamed: Q3.1 (B), R34.2

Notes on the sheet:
OLED display connector (I2C)
RESET and BOOT buttons
Breakout for remaining pins
To learn more about the boot mode selection, see documentation at https://txplo.re/esp32boot

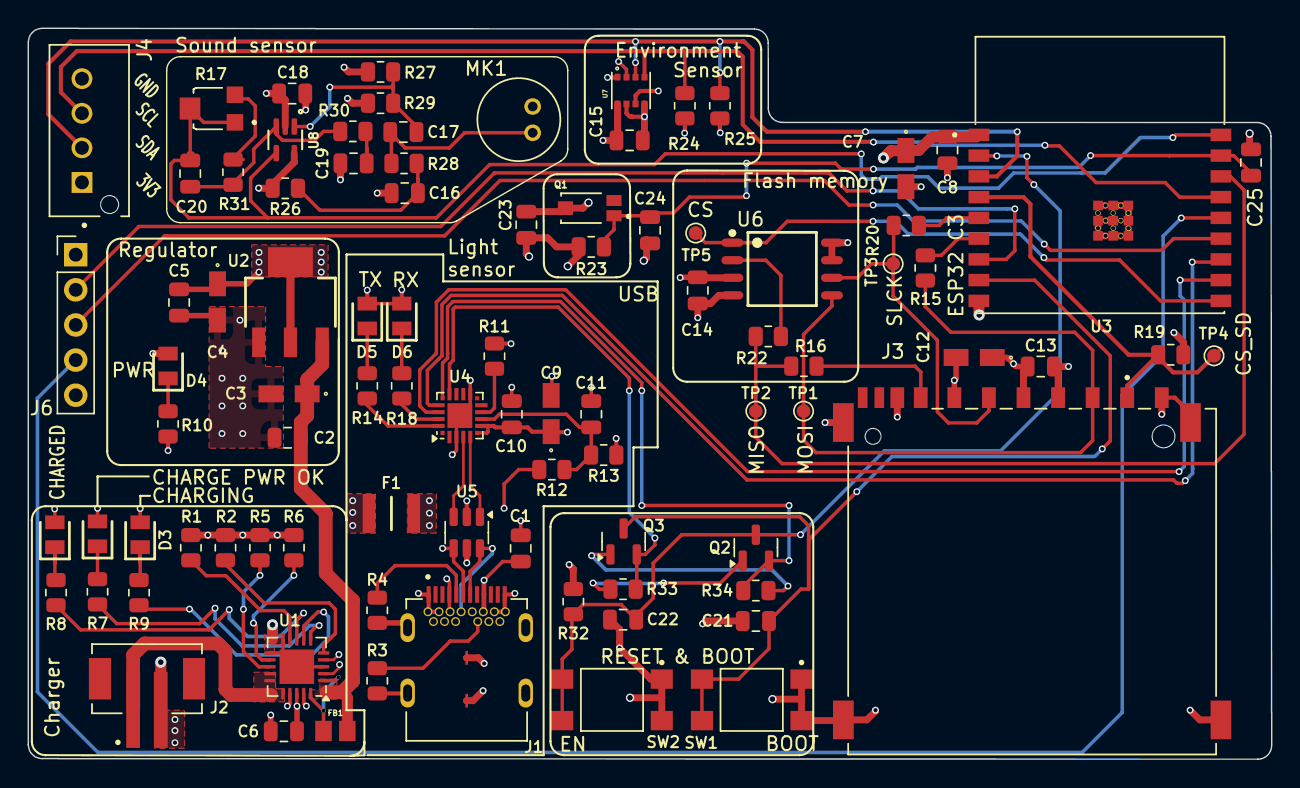
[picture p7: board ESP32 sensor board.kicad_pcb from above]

Board: 4 copper layers, 89.9 x 52.8 mm, 90 parts (0 on the bottom side), 60 nets.

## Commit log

2024-11-22 Starting integration of the ESP32.
    [ESP32-C3-02.kicad_sch]
2024-11-23 Completed first revision of the ESP32 and CP2102 integration.
    [ESP32 sensor board.kicad_sch, ESP32-C3-02.kicad_sch]
2024-11-23 Created the draft layout, and inserted available footprints.
    [ESP32 sensor board.kicad_pcb, ESP32 sensor board.kicad_sch, ESP32-C3-02.kicad_sch]
2024-11-28 Excluding various KiCad files from the repository.
2024-11-29 Added flash memory module and microsd module to the designed. Moved the libraries and datasheets in the project folder.
    [ESP32 sensor board.kicad_sch, ESP32-C3-02.kicad_sch]
2024-11-29 Added sensors to the schematic design.
    [ESP32-C3-02.kicad_sch, sensors.kicad_sch]
2024-11-30 Added an OLED I2C display connector, boot and reset buttons, and breakout for remaining pins.
    [0.96_OLED.kicad_pcb, 0.96_OLED.kicad_sch, 0.96_OLED_BOM.csv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]
2024-11-30 Remove deleted files
    [0.96_OLED.kicad_pcb, 0.96_OLED.kicad_sch, 0.96_OLED_BOM.csv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]
2024-12-03 Created netclasses and assigned nets.
    [ESP32 sensor board.kicad_sch]
2024-12-03 Completed symbol and footprint associations.
    [ESP32-C3-02.kicad_sch, sensors.kicad_sch, user_interface.kicad_sch]
2024-12-05 Small fixes.
    [ESP32 sensor board.kicad_sch, ESP32-C3-02.kicad_sch, sensors.kicad_sch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]
2024-12-06 Simplifying component values by removing units.
    [ESP32 sensor board.kicad_sch, ESP32-C3-02.kicad_sch, sensors.kicad_sch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]
2024-12-11 Changed the name of the project folder, no need for version number.
    [ESP32 sensor board.kicad_pcb, ESP32 sensor board.kicad_sch, ESP32-C3-02.kicad_sch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]
2024-12-11 Fixed lots of bugs.
    [ESP32 sensor board.kicad_pcb, ESP32 sensor board.kicad_sch, ESP32-C3-02.kicad_sch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]
2024-12-12 Configured the layout editor.
    [ESP32 sensor board.kicad_pcb, ESP32 sensor board.kicad_sch, ESP32-C3-02.kicad_sch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]
2024-12-12 Completed draft layout.
    [ESP32 sensor board.kicad_pcb, sensors.kicad_sch]
2024-12-12 Experimenting with lenght tuning of the USB data tracks.
    [ESP32 sensor board.kicad_pcb]
2024-12-12 Autorouting experiment. Layout is incomplete.
    [ESP32 sensor board.kicad_pcb]
2024-12-12 Trying routing, layout, and changed USB and battery connectors.
    [ESP32 sensor board.kicad_pcb, ESP32 sensor board.kicad_sch]
2024-12-12 Replaced the button, USB, bat connector with new symbols and footprints. Completed draft layout and routing.
    [ESP32 sensor board.kicad_pcb, ESP32 sensor board.kicad_pcb.backup.kicad_pcb, ESP32 sensor board.kicad_sch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]
2024-12-13 Removed redundant layout backup file.
    [ESP32 sensor board.kicad_pcb.backup.kicad_pcb]
2024-12-13 Added draft BOM.
    [BOM.xlsx]
2024-12-13 Replaced tantalum capacitors and LEDs.
    [ESP32 sensor board.kicad_pcb, ESP32 sensor board.kicad_sch, ESP32-C3-02.kicad_sch]
2024-12-14 Layout in progress.
    [ESP32 sensor board.kicad_pcb, ESP32-C3-02.kicad_sch]
2024-12-14 Added 3D models.
    [ESP32 sensor board.kicad_pcb]
2024-12-14 Completed layout and 3D models, next up is review everything.
    [ESP32 sensor board.kicad_pcb, ESP32-C3-02.kicad_sch]
2024-12-16 Completed draft of the layout.
    [ESP32 sensor board.kicad_pcb, ESP32 sensor board.kicad_sch, user_interface.kicad_sch]
2024-12-20 Replaced USB C receptacle with a different model. Repositioning components to better align with manufacturer recommendations.
    [ESP32 sensor board.kicad_pcb, ESP32 sensor board.kicad_sch, ESP32-C3-02.kicad_sch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]
2024-12-20 Work in progress, new layout and routing.
    [ESP32 sensor board.kicad_pcb, ESP32 sensor board.kicad_sch, ESP32-C3-02.kicad_sch]
2024-12-20 Moving thigns around.
    [ESP32 sensor board.kicad_pcb]
2024-12-21 Completed layout for v2.
    [ESP32 sensor board.kicad_pcb, ESP32 sensor board.kicad_sch]
2024-12-23 Introduced new parts that can be purchased for manufacturing by NextPCB. Corrected numerous issues.
    [BOM.xlsx, ESP32 sensor board.kicad_pcb, ESP32 sensor board.kicad_sch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]
2024-12-23 Updated U1 footprint to better match the component we can order from Microchip.
    [BOM.xlsx, ESP32 sensor board.kicad_pcb]
2024-12-26 Optimisation complete.
    [ESP32 sensor board.kicad_pcb, ESP32 sensor board.kicad_pcb.old.kicad_pcb, ESP32 sensor board.kicad_sch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]
2024-12-26 Removed old files.
    [ESP32 sensor board.kicad_pcb.old.kicad_pcb, ESP32 sensor board.kicad_sch.old.kicad_sch]
2024-12-27 Additional checks completed, and Gerbers exported for HQDFM. Looking good for manufacturing.
    [ESP32 sensor board-B_Cu.gbl, ESP32 sensor board-B_Mask.gbs, ESP32 sensor board-B_Paste.gbp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]
2025-01-23 Update LICENSE
    Now using the CERN-OHL-S (Strongly Reciprocal). This variant requires that any modifications or derivatives of the licensed material be distributed under the same license terms, ensuring that all der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
2025-02-28 Fixed and improved Schematic design:
    * Changed the buttons
    * Added a ferrite bead at the output of the charger to cut some possible noise.
    * Changed the values of R30, R31 and C19, and i add a 100K trimmer to set the gain from 25x to 125x.
    * Added C23, C24 and C25 in the photo sensor circuit
    [ESP32 sensor board.kicad_sch, ESP32-C3-02.kicad_sch, sensors.kicad_sch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]
2025-02-28 Added updated BOM file.
    [BOM.ods, BOM.xlsx]
2025-03-03 Completed symbol-footprint associations.
    [ESP32 sensor board.kicad_sch]
2025-03-03 Completed schematic fixes and updates. Continuing with the layout for Prototype #2.
    [ESP32-C3-02.kicad_sch, sensors.kicad_sch, user_interface.kicad_sch]
2025-03-03 Added updated BOM.
    [BOM.ods]
2025-03-03 Finished layout update for prototype #2.
    [ESP32 sensor board.kicad_pcb, sensors.kicad_sch, user_interface.kicad_sch]
2025-03-03 Added a diagram that shows the changes in prototype #2 in a graphical way.
2025-03-03 Swapped pins for CS_SD and MIC_OUT so that the microphone is connected to a usable ADC.
    [ESP32 sensor board.kicad_pcb, ESP32-C3-02.kicad_sch, user_interface.kicad_sch]
2025-03-03 Minor text adjustements.
    [ESP32 sensor board.kicad_pcb]
2025-05-12 Added missing data in BOM
    [BOM.ods]
2025-09-10 Set correct SW1 and SW2 symbols
    [user_interface.kicad_sch]
2026-06-29 Submitted BOM for assembly
    [BOM11.xlsx]
